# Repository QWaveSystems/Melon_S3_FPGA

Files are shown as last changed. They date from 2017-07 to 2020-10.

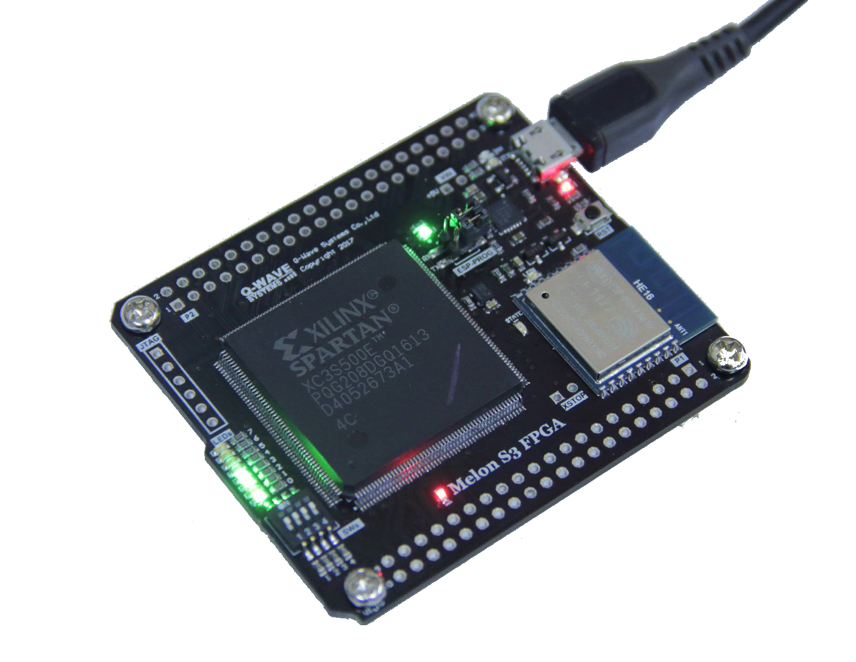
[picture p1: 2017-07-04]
Images/ms3.02.png

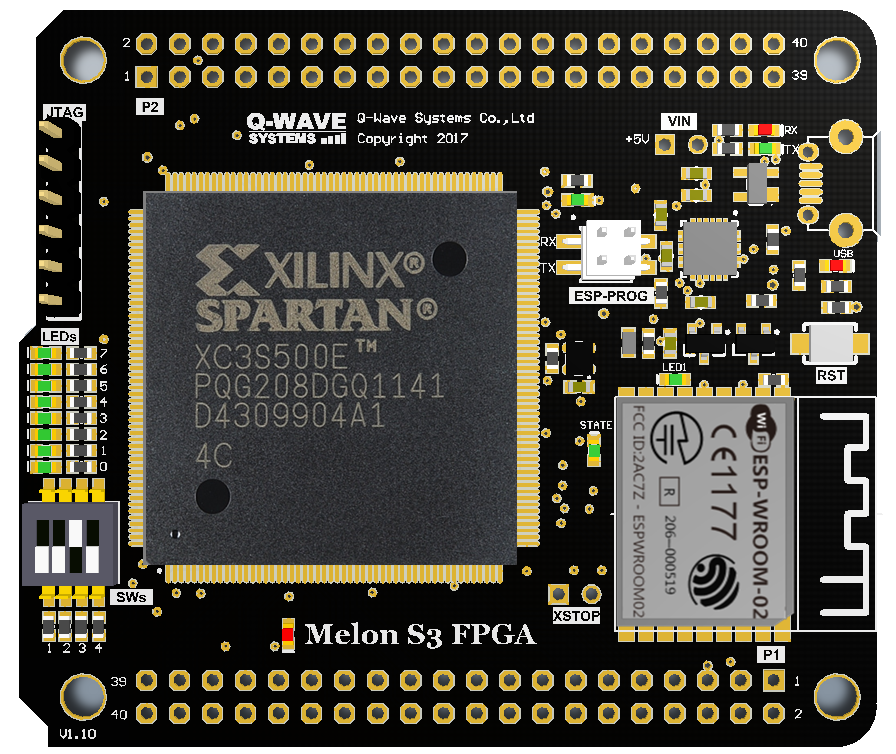
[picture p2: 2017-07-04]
Images/ms3.03.png

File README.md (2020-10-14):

# Melon S3 FPGA Development Board Hardware User Manual

# How to get a development board.

https://www.qwaveshop.com/en/product/340843/product-340843

# Community Support Forums

https://www.facebook.com/groups/244230302736445/

### Table of Contents
 
- [Introduction](#introduction)
- [Specification](#specification)
- [System Block Diagram](#system-block-diagram)
- [Board Overview](#board-overview)
- [ESP-PROG (TX/RX) Jumper Setting](#txrx-jumper-setting)
- [Pin Definition](#pin-definition)
- [Getting Started](#getting-started--starting-the-board-for-the-first-time)
- [OTA Programming (Upload .bit file to flash memory over the WiFi)](#ota-programming-upload-bit-file-to-flash-memory-over-the-wifi)
- [Write your own ESP8266 firmware.](#write-your-own-esp8266-firmware)
- [FPGA Development using Xilinx ISE Webpack](#fpga-development-using-xilinx-ise-webpack)
- [Install LabVIEW FPGA Driver](#install-melon-s3-fpga--labview-driver)
- [LabVIEW FPGA: Demo (Debug Mode over WiFi)](#labview-fpga-development-demo-debug-mode-over-wifi)
- [LabVIEW FPGA: Create a build specification to build a .bit file](#labview-fpga-development-create-a-build-specification-to-generate-a-bit-file)
- [LabVIEW FPGA: Additional Tools](#labview-fpga-development-additional-tools)
- [LabVIEW FPGA: Export .bit file](#labview-fpga-development-export-bit-file)
- [LabVIEW FPGA: Generate Control define for Arduino](#labview-fpga-development-generate-control-define-for-arduino)
- [LabVIEW FPGA: Host-Target Architecture: (Arduino MCU) <-> (FPGA)](#labview-fpga-development-host-target-architecture-arduino-mcu---fpga)
- [LabVIEW FPGA: Host-Target Architecture: (Raspberry Pi CPU) <-> (FPGA)](#labview-fpga-development-host-target-architecture-raspberry-pi-cpu---fpga)
- [Mechanical Specification](#mechanical-specification)
- [Download Board design files](#download-board-design-files)
- [License](#license)
- [Maintainer](#maintainer)

***

## Introduction

 The **Melon S3 FPGA is an open-source hardware (OSHW)**, expandable development board perfect for the learning digital circuit design and prototyping of your unique ideas. You can customize the capabilities of the FPGA with snap-on 40-pin "Raspberry Pi HAT". There are serveral shilds in the market offers a low cost module that can be purchased off the shelf. These shiled modules can be plugged directly to the Melon S3 FPGA board for the creation of powerful embedded and digital system applications.



## Specification

   - OTA (Over-The-Air) Download.bit file to FPGA over the WiFi
   - **Xilinx Spartan 3E FPGA (PQG208) - 500K gates**,
(73Kb Distributed RAM, 4 Digital Clock Manager (DCM), 20 Multipliers (18x18), 360 Kb Block RAM)
   - Onboard USB-UART (Silicon Labs) CP2104 for Configuration, Debugging and Power.
   - **MCU WROOM-02 (ESP8266), WiFi 2.4GHz + 32-bit MCU (Arduino Compatible)** Clock 80MHz, 50KB RAM, Integrated TCP/IP protocol stack.
   - Flash **4MB SPI Flash** which is **1MB for MCU Firmware** and **3MB for FPGA Bit space**.
   - 8 Users LEDs, 4 DIP Switch user button, 1 Reset button
   - Onboard FPGA clock 50MHz
   - GPIOs 56 PINs **3.3V Tolerant** - 40 PINs x2 (Raspberry Pi 40 PINs Compatible)
   - JTAG Port (*Optional for Program/Debugging)
   
   

[Back to top](#melon-s3-fpga-development-board-hardware-user-manual)

## System Block Diagram



In addition, The Melon S3 FPGA can be programmed using established development tools, such as [Xilinx ISE (Free: Webpack)](https://www.xilinx.com/products/design-tools/ise-design-suite/ise-webpack.html), [MATLAB HDL Coder/HDL Verifier](https://www.mathworks.com/solutions/hdl-code-generation-verification.html) and [National Instruments LabVIEW FPGA Toolkit](http://www.ni.com/labview/fpga/). Lastly, MCU ESP8266 (WROOM-02) can be programmed using Arduino IDE.

[Back to top](#melon-s3-fpga-development-board-hardware-user-manual)
  
## Board Overview
 
 **Front Side**
 

 
| Position | Reference | Description |
|:---:|:---:|:---|
| 1 | JTAG Port | Optional for Programing & Debuging using Xilinx ISE Software|
| 2 | FPGA | Xilinx FPGA Spartan 3E 500K|
| 3 | LEDs | x8 LED (Green)|
| 4 | DIP SWs | x4 DIP Switches|
| 5 | Pwr LED | 3.3V Power LED (Red)|
| 6 | XSTOP Jumper| FPGA code will STOP if Jumper added (Size 2.5"), Using this jumper as a FPGA stop pin (No jumper by default)|
| 7 | Status LED | User define LED (Green) at GPIO15 of ESP8266|
| 8 | MCU | WiFi SoC (ESP8266) Flash 4MB Version|
| 9 | Oscilator | ABRACON 50 MHz onboard oscilator (50ppm)|
| 10 | LED1 | User define LED (Green) at GPIO2 of ESP8266, This LED will be flashing during upload firmware to ESP8266|
| 11 | Reset Btn | Reset Button for ESP8266|
| 12 | TX/RX Jumper | TX/RX Jumper of ESP8266 and USB CP2104 (Size 2.0"), Refer Jumper setting section|
| 13 | USB IC | CP2104 UART to USB IC|
| 14 | USB LED | USB Plug-in LED Status (VUSB)|
| 15 | Done LED | FPGA Status LED if .bit file downloaded to FPGA without error|
| 16 | VIN 5V | External Power supply +5V can powered the board from this pin|
| 17 | TX/RX LEDs  | TX/RX LED Status of USB IC (CP2104)|
| 18 | USB Connector| USB Connector for +5V input for powered the board or Debug/Programming port for ESP8266|

[Back to top](#melon-s3-fpga-development-board-hardware-user-manual)

**Bottom Side** (Solder pad jumper for the users are willing to use with **Raspberry Pi Shileds**)



| Position | Reference | Description |
|:---:|:---:|:---|
| 1 | (JP2) RPi 3.3 V Jumper| Solder pad Jumper is "Open" by Default, But once the Melon FPGA and Raspberry Pi **Shields** stacked together **at P1 Port**, You can powered RPi **Shileds** board at 3.3V P1:1,P1:17 (3V3_RP) by using the power VUSB (5V) or VIN (5V) from Melon FPGA board, by setting the Jumper "Closed (Soldered)", Refer schematic for more information|
| 2 | HSWAP Jumper | Set the default state of FPGA Pins, Solder pad jumper is "Open"= Pull-down (by Default), Set the jumper pad to "Closed, (Soldered)"= All the FPGA pins are Pull-Up.|
| 3 | (JP1) Rpi 5V Jumper  |  Solder pad Jumper is "Open" by Default, But once the Melon FPGA and Raspberry Pi **Shields** are stacked together **at P1 Port**, if you want to powered RPi **Shields**  P1:2,P2:4 (5V_RP) by using the power VUSB (5V) or VIN (5V) from Melon FPGA board, by setting the Jumper "Closed (Soldered)", Refer schematic for more information|

[Back to top](#melon-s3-fpga-development-board-hardware-user-manual)

## TX/RX Jumper Setting

"ESP-PROGRAM" TX/RX Jumper is set to "Open" by Default, In order to re-program ESP8266 firmware, The both jumpers (TX/RX) need to be inserted (Closed).

USB TX/RX and ESP TX/RX pins also routed to FPGA refer the diagram below, You can writed the FPGA code to set jumper internally. In this case you can re-program the ESP8266 firmware without any jumpers.



[Back to top](#melon-s3-fpga-development-board-hardware-user-manual)

## Pin Definition



**Port1**

FPGA Pin Number (Pxx) vs Connector Pins **(RPi shileds can be connected to this port)**

| Description | Pin Number | Pin Number | Description |
|:---:|:---:|:---:|:---:|
| **+3V3_RP** Using with RPi shields need to set solder pad jumper at bottom side |**1** |**2** |**+5V_RP** Using with RPi shields need to set solder pad jumper at bottom side|
| P50 |3 |**4** |**+5V_RP** Using with RPi shields need to set solder pad jumper at bottom side|
| P49 |5 |**6** |**Ground**|
| P48 |7 |8 |P47|
| **Ground** |**9** |10 |P42|
| P41 |11 |12 |P40|
| P39 |13 |**14** |**Ground**|
| P36 |15 |16 |P35|
| **+3V3_RP** Using with RPi shields need to set solder pad jumper at bottom side |**17** |18 |P34|
| P35 |19 |**20** |**Ground**|
| P31 |21 |22 |P30|
| P29 |23 |24 |P28|
| **Ground** |**25** |26 |P25|
| P24 |27 |28 |P23|
| P22 |29 |**30** |**Ground**|
| P19 |31 |32 |P18|
| P16 |33 |**34** |**Ground**|
| P15 |35 |36 |P12|
| P11 |37 |38 |P9|
| **Ground** |**39** |40 |P8|
   
 **Port 1** : The FPGA pin constraints (.ucf) for Xilinx ISE and FPGA IO for LabVIEW aslo provide. 
   
     
  
[Back to top](#melon-s3-fpga-development-board-hardware-user-manual)
  
**Port2**

FPGA Pin Number (Pxx) vs Connector Pins

| Description | Pin Number | Pin Number | Description |
|:---:|:---:|:---:|:---:|
| **+3V3** |**1** |**2** |**+5V**|
| P153 |3 |**4** |**+5V**|
| P152 |5 |**6** |**Ground**|
| P150 |7 |8 |P151|
| **Ground** |**9** |10 |P147|
| P146 |11 |12 |P145|
| P144 |13 |**14** |**Ground**|
| P139 |15 |16 |P140|
| **+3V3** |**17** |18 |P138|
| P137 |19 |**20** |**Ground**|
| P133 |21 |22 |P132|
| P129 |23 |24 |P128|
| **Ground** |**25** |26 |P127|
| P126 |27 |28 |P123|
| P122 |29 |**30** |**Ground**|
| P120 |31 |32 |P119|
| P116 |33 |**34** |**Ground**|
| P115 |35 |36 |P113|
| P112 |37 |38 |P109|
| **Ground** |**39** |40 |P108|
   
 **Port 2** : The FPGA pin constraints (.ucf) for Xilinx ISE and FPGA IO for LabVIEW aslo provide.  
   
    
 
[Back to top](#melon-s3-fpga-development-board-hardware-user-manual)
 
## Getting Started : Starting the board for the first time

   - Plug-in the USB cable to the USB computer port to powered the board, You will get the 8-bit counter (up) at onboard LEDs with speed around 100ms.

  

   - Debugging the data at COM port, Put the "ESP-PROG" both jumper to the "Closed" position,
   
   
     
   - Open the Serial Monitor software > Select COM port > Set the buad rate to **"115200"**,Then pressed the "RESET" button on the board. This is what you will get from serial monitor.
   
     
   
   - Right now the board is act like **WiFi Access Point name "Melon-xxxxx"**, Re-scanning the WiFi, its will be appear on the network.
   - Connect to the **"Melon-xxxxx"** using the default password **"88888888"**
   - After that open the web browser, Then goto main webpage **"192.168.4.1"**
   
        
 
 [Back to top](#melon-s3-fpga-development-board-hardware-user-manual)
 
   - There are several command that already created for you to working with File Systems over the web browser. It is written using Arduino C/C++ ,Refer to shipped firmware source code in this repository ("Firmware" folder).
   
     - **./files**  (List the files inside flash memory)
     - **./startup** (Set the config file to load FPGA code at startup)
     - **./unstartup** (Unset the config file to load FPGA code at startup)
     - **./delete?file=[File Name]** (For example : http://192.168.4.1/delete?file=xx.bit)
     - **./[File Name]** To view or download the file (For example : http://192.168.4.1/xx.json)
   
   - For example we will try to lists the files that currently stored in flash memory. Type : **"http://192.168.4.1/files** You will see there are serveral files, The important one is **"Fpga.bit"** file, It's a FPGA bit file that currently running on the board right now. 

 

## OTA Programming (Upload .bit file to flash memory over the WiFi)
   
   - Download the .bit file from **"Bit_File/Fpga.bit"** from this repository. Save it in your local computer. (*It is a .bit file of 8-bit counter circuit that shipped with the board)*
   - Click the **"Choose File"**, > Select the **"Fpga.bit"**. > Click **"Update"**, The bit file will be transfer over the WiFi then upload diretly to flash memory, (You will get status "*Update Success!*", If it not please try again), After that board it will reset once, Finally you will see the FPGA start-up with the 8-bit counter circuit again.
   


[Back to top](#melon-s3-fpga-development-board-hardware-user-manual)

## Write your own ESP8266 firmware.
### (1/2) Install Arduino “QWAVE ESP8266 Board Package”

   - Download a Arduino IDE 1.8.x from "https://www.arduino.cc/en/Main/Software"
   - Goto "File > Preferences", Then add "http://ftp1.qwavesys.com/lvembedded/package_qwavesys_v2_index.json" > Click OK
   


 
   
   - Goto "Tools > Board> Boards Manager ", Install "Embedded LabVIEW Arduino by Qwavesys"
   
 
 
  
   
   - Once the installation finished, You can find the "Qwave ESP8266 (LabVIEW)" board.



[Back to top](#melon-s3-fpga-development-board-hardware-user-manual)

### (2/2) Start Writing your own ESP8266 firmware.

   - The shipped Melon S3 MCU firmware is located at **"Firmware/Firmware-MelonS3-v.0.3.ino"** from this repository, Open it with Arduino IDE. 
   
   - Let's modify the WiFi AP name to **"Melon-[Your Name]"** to indicate that this is your board in the WiFi network, You can change default password, if you want to..
   
   
   
[Back to top](#melon-s3-fpga-development-board-hardware-user-manual)
   
   - In order to program ESP8266, The jumper setting must be in the right position, . In this case I will leave both jumpers opened (Removed), Because FPGA shipped example bit file is already routed ESP TX/EX <----> USB TX/RX inside FPGA chip. Refer jumber setting section. [TX/RX Jumper Setting](#txrx-jumper-setting)
   
   - Connect the board to development PC, Select **"Qwave ESP8266 (LabVIEW)"** board, Speed **"921600"** (Test with Max Speed,If it not working try reduce the speed down to 115200), Select **COM port**.
   
   
   
   

## FPGA Development using Xilinx ISE Webpack

 [ISE® WebPACK™](https://www.xilinx.com/products/design-tools/ise-design-suite/ise-webpack.html) design software is the industry´s only FREE, fully featured front-to-back FPGA design solution. ISE WebPACK is the ideal downloadable solution for FPGA and offering HDL synthesis and simulation, implementation, device fitting, and JTAG programming. ISE WebPACK delivers a complete, front-to-back design flow providing instant access to the ISE features and functionality at no cost. Xilinx has created a solution that allows convenient productivity by providing a design solution that is always up to date with error-free downloading and single file installation. **After generated .bit file you can then upload it to the Melon S3 FPGA via WiFi.**
 
 - The shipped example for Xilinx ISE VHDL project is located at **"Example_VHDL/Test_LED.zip"** from this repository, Open it with Xilinx ISE. Refer the setting below **Spartan3E , XC3S500E, PQ208, Speed Grade (-4)**
 
   
   
  - At the **LED_SW.vhd**, it is very simple VHDL example the reading the status of DIP switch and display at onboard LEDs.
  
   
  
  - The **Melon_S3.ucf** files also provide for pin constraints.
  
   
   
   - After run **Synthesize > Translate > Place &Route > Generate bit file** , Then you will get **led_sw.bit**, Please rename to "**Fpga.bit**", Then you can use [OTA Programming (Upload .bit file to flash memory over the WiFi)](#ota-programming-upload-bit-file-to-flash-memory-over-the-wifi) method to download a bit file to flash memory and run at FPGA.
   
   
      
[Back to top](#melon-s3-fpga-development-board-hardware-user-manual)

## Install Melon S3 FPGA : LabVIEW Driver

The [NI LabVIEW FPGA Module](http://www.ni.com/labview/fpga/) extends the LabVIEW graphical development platform to target FPGAs. LabVIEW FPGA gives developers the ability to more efficiently and effectively design complex systems by providing a highly integrated development environment, a large ecosystem of IP libraries, a high-fidelity simulator, and debugging features.
 
   - Before install LabVIEW driver , Please close all LabVIEW application. In this tutorial is assumed that you already have **LabVIEW 2014 (32bit) & LabVIEW 2014 FPGA Toolkit (For Windows)** installed in local machine.

   - Extract the folder **QwaveSys** to path. "C:\Program Files (x86)\National Instruments\LabVIEW 2014\Targets\NI\FPGA\QwaveSys"

   

   - Extract the folder "**MelonS3**" to path. "C:\Program Files (x86)\National Instruments\LabVIEW 2014\vi.lib\FPGAPlugInAG\Melon-S3"

   
   
   - At Windows Dev Machine: Copy "**QwaveFpgaLv.dll**" to systems path. "C:\Windows\System32\QwaveFpgaLv.dll"

   

   - **Remove "resource_cache.xml"** the file below, Before staring LabVIEW ONLY for the first time use. "C:\Program Files (x86)\National Instruments\LabVIEW 2014\Targets\NI\FPGA\resource_cache.xml"

   

   - Extract the folder "**HDL**" to path. "C:\Program Files (x86)\National Instruments\LabVIEW 2014\rvi\HDL"

   

   - Start **LabVIEW > Create LabVIEW Empty Project**, Under **"My Computer"** Select **"Target and Device**, you will find **"Melon-S3" under "3rd Party group"**
   
   
   
   
   
   - Right click at **"Melon-S3"** select **"New > FPGA I/O"** you will find available IOs for Melon-S3 ready to use within the project. Add them all if you want.
   
   
   
   
 
 [Back to top](#melon-s3-fpga-development-board-hardware-user-manual)

## LabVIEW FPGA Development: Demo (Debug Mode over WiFi)

  - The shipped example for LabVIEW FPGA is located at **"Example_LabVIEW/Test_Counter.zip"** from this repository, Open the project (**LED.lvproj**) file with LabVIEW.
 
  - Connect development PC with "**Melon-S3-xx**" WiFi AP. Refer to this step [Getting Started](#getting-started--starting-the-board-for-the-first-time)
  
  - Clcik **Run** button, Then observed the LabVIEW front panel and Onboard LEDs, Then you can adjust the **Count(mSec)** value to see the result in debugging mode.
    
  

[Back to top](#melon-s3-fpga-development-board-hardware-user-manual)

## LabVIEW FPGA Development: Create a build specification to generate a .bit file.

   -  **Right Click** at the VI (.vi) > **Create Build Specification**
  
  
  
   -  Under **Build Specification** > **Right Click** > Select : **Properties**
  
  
    
   -  Select **Run when loaded to FPGA**
    
  
   
   -  **Right Click** then, Select **Build**
   
  
   
   -  Select the **Use the Local Compile server** or Network/Cloud server. ([NI LabVIEW 2014 FPGA Module Xilinx Compilation Tools for Windows](http://www.ni.com/download/labview-fpga-module-2014/4845/en/) is required for local compilation. After finished you will get the output bit file at **"FPGA Bitfiles"** folder.
   
  
  
  
    
  

[Back to top](#melon-s3-fpga-development-board-hardware-user-manual)

## LabVIEW FPGA Development: Additional Tools.

   - **Right Click at the VI** you will get additional tools fo Melon S3 FPGA:
     
        - **Gen Bit File...** (Generate a bit file from build specification)
        - **Download VI To Flash Memory** (Download bit file to flash memory over WiFi, This will be done automatically.)
        - **Set FPGA Download As Startup** (Set FPGA code at startup, This action will be set "startup=1" at config.json file)
        - **Unset FPGA Download As Startup** (Unset FPGA code at startup, This action will be set "startup=0" at config.json file)
        - **Get Controls Define For Arduino** (Lists all LabVIEW front panel/controls for Arduino interface, Refer more detail to the next topic)
         - **Reboot** To view or download the file (This will send FPGA "reboot" command to the Melon FPGA board)

  

[Back to top](#melon-s3-fpga-development-board-hardware-user-manual)

## LabVIEW FPGA Development: Export .bit file.

   -  Select **"Gen Bit File.."** function, Then you will get **Fpga.bit** locaed at "FPGA Bitfiles" folder.

  

[Back to top](#melon-s3-fpga-development-board-hardware-user-manual)

## LabVIEW FPGA Development: Generate Control define for Arduino.

  -  Select **"Get Controls Define For Arduino"** function, Then you will get front panel control/indicator define to use in Arduino Code, Copy them and place at the top of Arduino C/C++ code. Refer next topic for example.

  

  

[Back to top](#melon-s3-fpga-development-board-hardware-user-manual)

## LabVIEW FPGA Development: Host-Target Architecture: (Arduino MCU) <-> (FPGA).

Using Arduino IDE you can write your own firmware running in MCU (WROOM-02), This allows your FPGA designs to talk to the microcontroller, giving you develop the MCU + FPGA for co-processing application.

  

[Back to top](#melon-s3-fpga-development-board-hardware-user-manual)

## LabVIEW FPGA Development: Host-Target Architecture: (Raspberry Pi CPU) <-> (FPGA).

  

[Back to top](#melon-s3-fpga-development-board-hardware-user-manual)

## Mechanical Specification

   

## Download Board design files

PDF https://github.com/QWaveSystems/Melon_S3_FPGA/tree/master/PDF

Schematic & PCB https://github.com/QWaveSystems/Melon_S3_FPGA/tree/master/Schematic_PCB

Firmware (Arduino C/C++) https://github.com/QWaveSystems/Melon_S3_FPGA/tree/master/Firmware

**Xilinx ISE support files**

https://github.com/QWaveSystems/Melon_S3_FPGA/blob/master/UCF%20File/Melon_S3.ucf

**Xilinx ISE project examples**

https://github.com/QWaveSystems/Melon_S3_FPGA/tree/master/Example_VHDL

**LabVIEW FPGA (2014) Examples**

8 bit Counter Example https://github.com/QWaveSystems/Melon_S3_FPGA/tree/master/Example_LabVIEW

8 bit Counter with Raspberry Pi Interface https://github.com/QWaveSystems/Melon_S3_FPGA/tree/master/Example_LabVIEW_RaspberryPi_LINX

[Back to top](#melon-s3-fpga-development-board-hardware-user-manual)

## LICENSE

-Schematics and PCB ﬁles is licensed under a Creative Commons Attribution-ShareAlike 4.0 International License.
You should have received a copy of the license along with this work. If not, see: http://creativecommons.org/licenses/by-sa/4.0

[Back to top](#melon-s3-fpga-development-board-hardware-user-manual)

## Maintainers

Amornthep Phunsin <amornthep@qwavesys.com>

[Back to top](#melon-s3-fpga-development-board-hardware-user-manual)

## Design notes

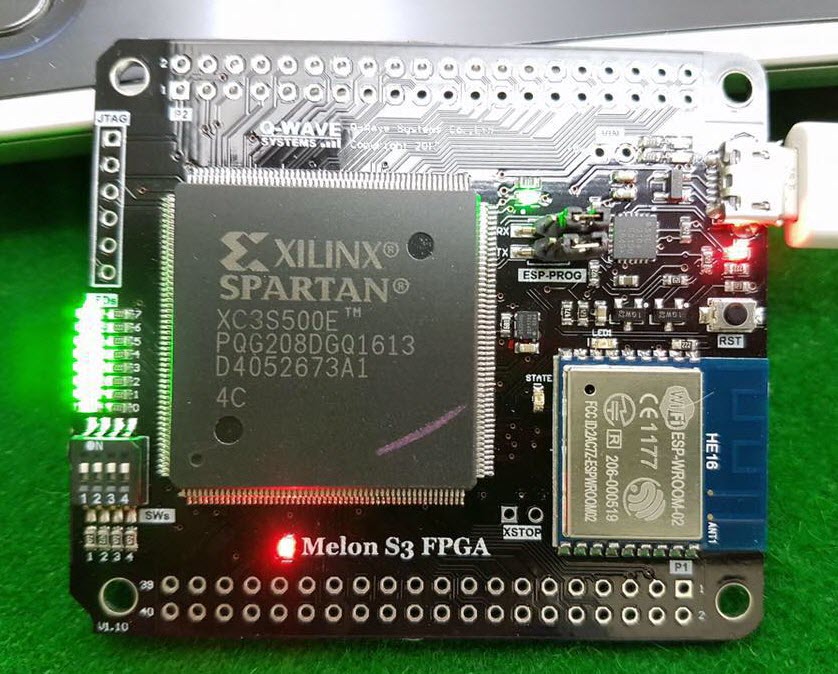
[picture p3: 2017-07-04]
Images/ms3.01.jpg

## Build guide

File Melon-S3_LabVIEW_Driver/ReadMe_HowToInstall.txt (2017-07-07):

Before install driver , Please close all LabVIEW application.

1. Extract the folder "QwaveSys" to below path
C:\Program Files (x86)\National Instruments\LabVIEW 2014\Targets\NI\FPGA\QwaveSys

2. Extract the folder "MelonS3" to below path 
C:\Program Files (x86)\National Instruments\LabVIEW 2014\vi.lib\FPGAPlugInAG\Melon-S3

3. At Windows Dev Machine: Copy "QwaveFpgaLv.dll" to systems path.
C:\Windows\System32\QwaveFpgaLv.dll

4.Remove the file below, Before staring LabVIEW only for the first time use.
C:\Program Files (x86)\National Instruments\LabVIEW 2014\Targets\NI\FPGA\resource_cache.xml

5.Extract the folder "HDL" to below path.
C:\Program Files (x86)\National Instruments\LabVIEW 2014\rvi\HDL

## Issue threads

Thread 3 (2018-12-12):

melons3 firmware problem with qwavefpga.h

imangholizadeh, 2018-12-12:
I program my esp8266 board (ESP8266 ESP-12E NODEMCU ) with Firmware-MelonS3-v.0.3.ino without any change and  then i cant see any access point. i debuged code and i saw  functions that realated to qwavefpga.h  not runing. why?
i dont have wroom-2 and i want to use ESP8266 ESP-12E NODEMCU instad of  wroom-2.can i do this? how?

pamornthep, 2018-12-13:
The code "Firmware-MelonS3-v.0.3.ino " haven't tested with ESP-12E. I am not sure what is the problem. I only do tested with WROOM-02, The WROOM-02 module is difference from ESP-12E in term of hardware spec,flash memory,pin assignment and etc...

imangholizadeh, 2018-12-13:
thanks for your replay. I know WROOM-02 module is difference from ESP-12E and i change spec pin configuration and etc ... but no answer. my problem is There are no WROOM-02 in my country, and if they exist, they are much more expensive than ESP-12E. if i has qwavefpga.ccp i can write this firmware for other arduino board but in melon s3 project qwavefpga.ccp is hidden in static library "libqwavesys.a " located in "\qwavesys\hardware\esp8266\2.3.0-2\tools\sdk\lib" and i can not access to source of "libqwavesys.a " . if melon s3 project is open source  I expected that is not hidden. If you can help me anyway, I will thank you for it.

johnmayer21, 2018-12-23:
@imangholizadeh They can not tell you this because they are just copying our work and they are not aware of it themselves.
This science is only available to our company, and they will always be illegal in our area.

johnmayer21, 2018-12-23:
@imangholizadeh They can not tell you this because they are just copying our work and they are not aware of it themselves.
This science is only available to our company and they will always follow us.

sdikiy, 2019-02-06:
Very strange situation.
The project claims GPL support, and in fact most of the code is hidden in a static library.
https://github.com/QWaveSystems/Melon_S3_FPGA/blob/master/Firmware/License.md
Very strange project ...

imangholizadeh, 2019-02-14:
Yes Very strange project ...and we can not use that because all required code is hidden in a static library.
if you want to share some information with together you can send me email.
Email address: imangholizadeh68@gmail.com

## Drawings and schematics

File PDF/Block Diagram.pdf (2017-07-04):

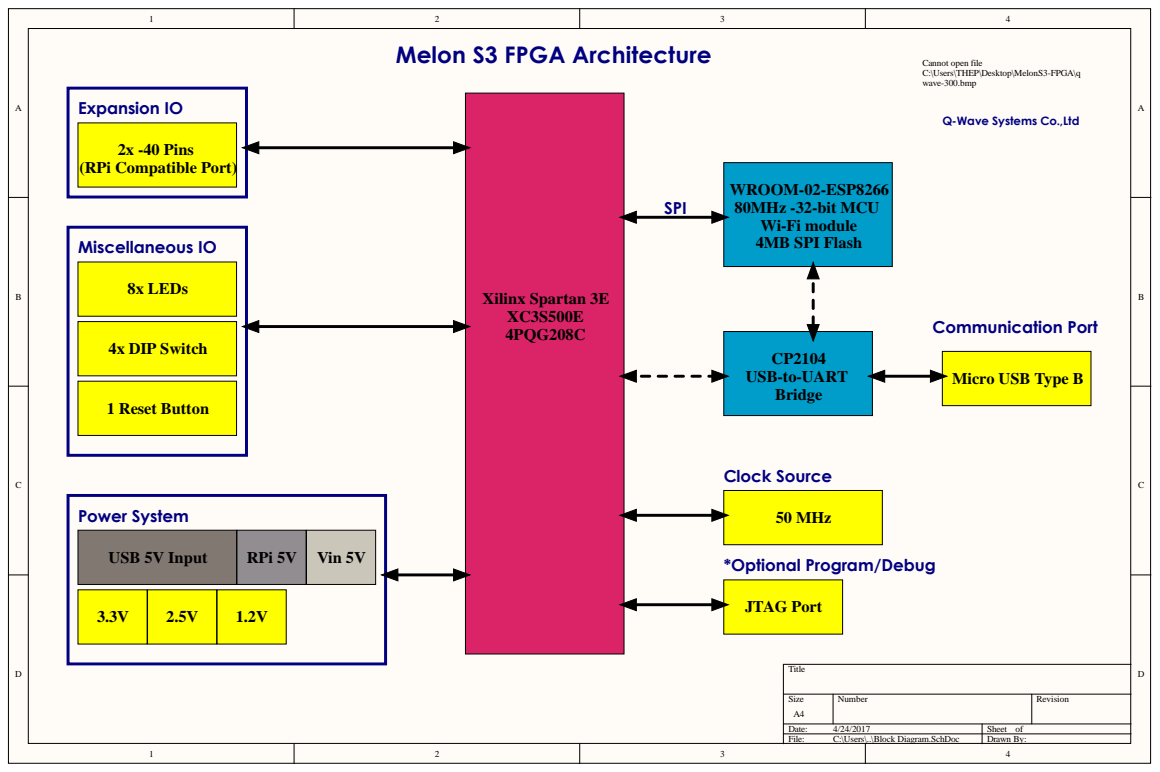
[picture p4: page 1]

C:\Users\THEP\Desktop\MelonS3-FPGA\q
wave-300.bmp

Q-Wave Systems Co.,Ltd

USB 5V Input | RPi 5V | Vin 5V

Size A4 | Number | Revision

Date: 4/24/2017 | Sheet of
File: C:\Users\..\Block Diagram.SchDoc | Drawn By:

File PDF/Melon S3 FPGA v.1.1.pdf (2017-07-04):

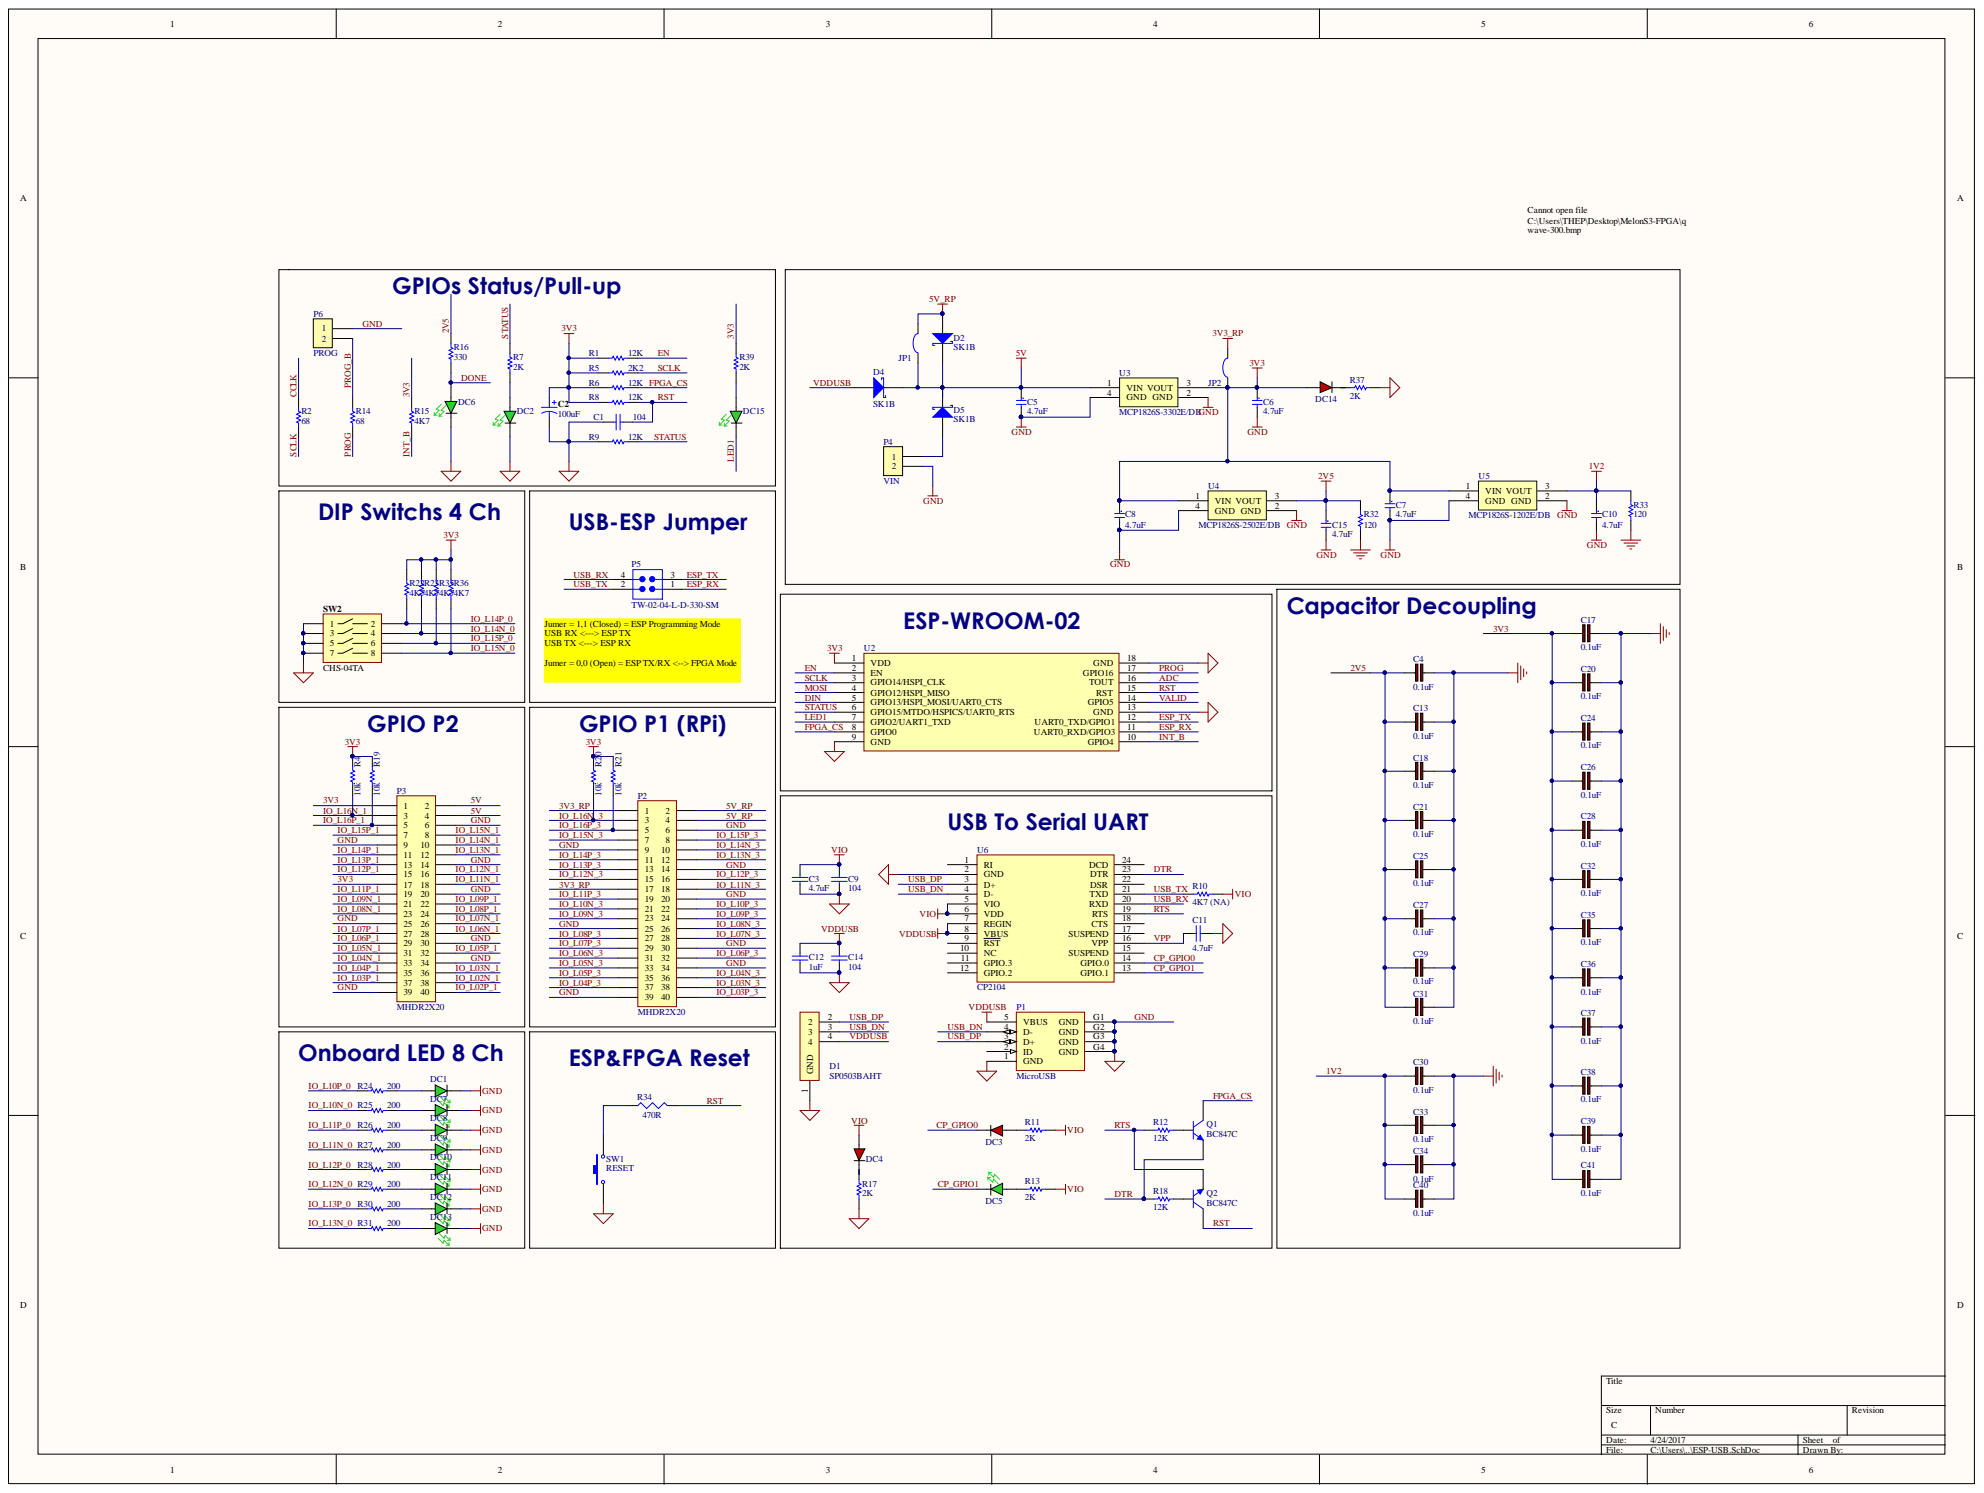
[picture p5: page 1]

Cannot open file
C:\Users\THEP\Desktop\MelonS3-FPGA\q
wave-300.bmp

GPIOs Status/Pull-up

Jumer = 1,1 (Closed) = ESP Programming Mode
USB RX <---> ESP TX
USB TX <---> ESP RX

IO_L15P_0
IO_L15N_0

Jumer = 0,0 (Open) = ESP TX/RX <--> FPGA Mode

GPIO P2 3V3 P3 | GPIO P1 (RPi) 3V3 | STATUS LED1 | GPIO15/MTDO/HSPICS/UART0_RTS 6 GPIO2/UART1_TXD 7 | ESP_TX

USB To Serial UART


C:\Users\THEP\Desktop\MelonS3-FPGA\q
wave-300.bmp

Q-Wave Systems Co.,Ltd

USB 5V Input | RPi 5V | Vin 5V

Size A4 | Number | Revision

Date: 4/24/2017 | Sheet of
File: C:\Users\..\Block Diagram.SchDoc | Drawn By:

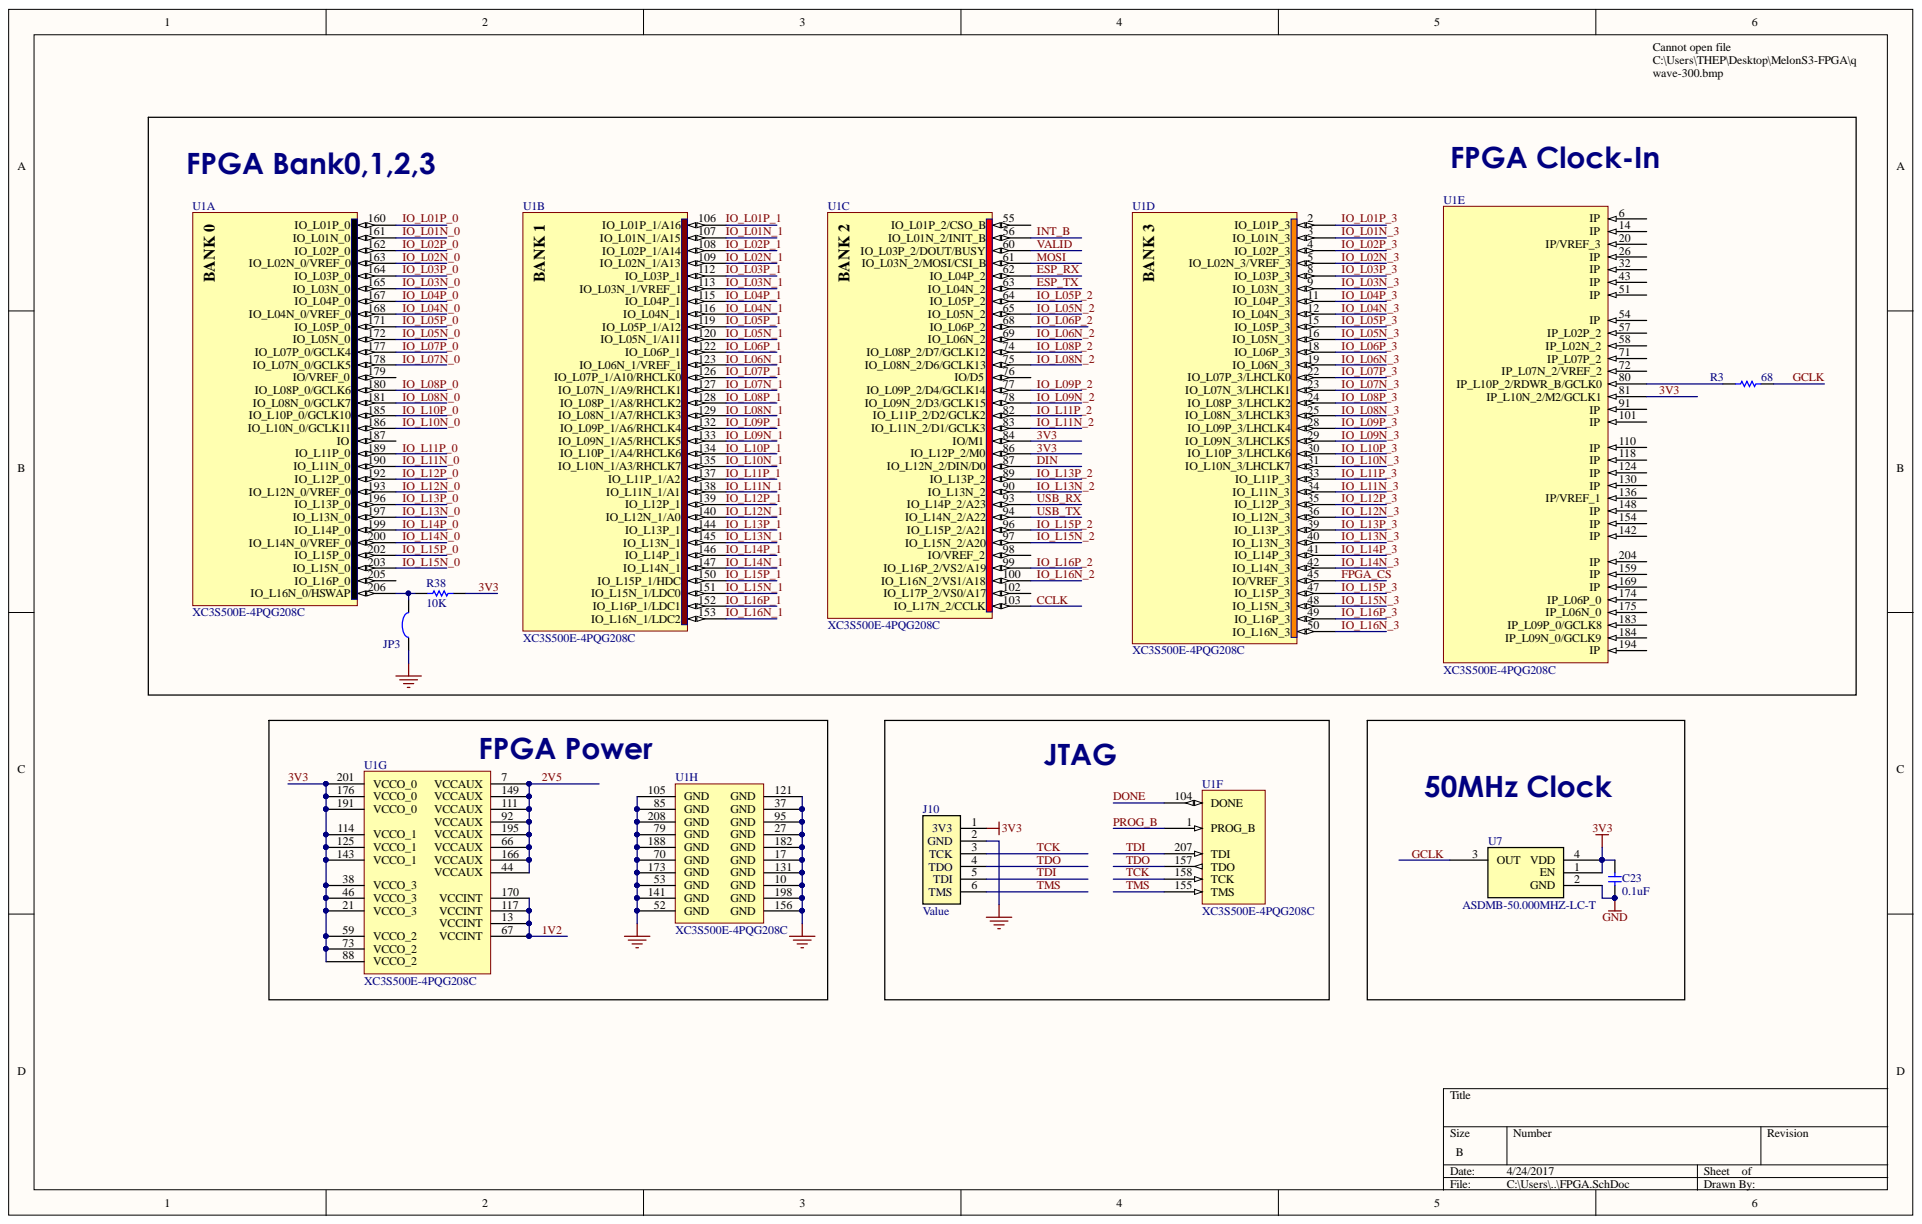
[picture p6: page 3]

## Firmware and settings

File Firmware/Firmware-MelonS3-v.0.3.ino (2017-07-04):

// Qwave ESP8266 (LabVIEW) 4M(3M SPIFFS)

#include <ESP8266WiFi.h>
#include <WiFiClient.h>
#include <ESP8266WebServer.h>
#include <WiFiUdp.h>
#include <ArduinoJson.h>
#include <FS.h>

// remove comment when using soft AP mode
#define SOFT_AP
#define DEVICE_NAME "QWAVE"

#define DBG_OUTPUT_PORT   Serial

#ifdef SOFT_AP
// Soft-AP Config
String ssid = "MelonS3";
String password = "88888888";
#else
// Network
String ssid = "";
String password = "";
#endif

#include "QwaveFpga.h"
QwaveFpga Fpga;
String FpgaStart;

extern "C" {
  #include "user_interface.h"
}

const char* bitfileupload = "<h2>FPGA Bit File Upload</h2><form method='POST' action='/' enctype='multipart/form-data'><input type='file' name='update'><input type='submit' value='Update'></form>";

ESP8266WebServer server(80);
WiFiUDP udp;

// buffers for receiving and sending data
char packetBuffer[UDP_TX_PACKET_MAX_SIZE]; //buffer to hold incoming packet,
String ReplyBuffer;

// local port to listen for UDP packets
unsigned int localPort = 4097;

File fsUploadFile;

String inputString = "";         // a string to hold incoming data
boolean stringComplete = false;  // whether the string is complete

String macToStr(const uint8_t* mac)
{
  String result;
  for (int i = 0; i < 6; ++i) {
    result += String(mac[i], 16);
  }
  result.toUpperCase();
  return result;
}

String loadConfig(String fname, String field) {
  File configFile = SPIFFS.open("/"+fname, "r");
  if (!configFile) {
    DBG_OUTPUT_PORT.println("Failed to open "+fname+" file!");
    return "";
  }

  size_t size = configFile.size();
  if (size > 1024) {
    DBG_OUTPUT_PORT.println("Config file size is too large");
    return "";
  }

  // Allocate a buffer to store contents of the file.
  std::unique_ptr<char[]> buf(new char[size]);

  // We don't use String here because ArduinoJson library requires the input
  // buffer to be mutable. If you don't use ArduinoJson, you may as well
  // use configFile.readString instead.
  configFile.readBytes(buf.get(), size);

  StaticJsonBuffer<200> jsonBuffer;
  JsonObject& json = jsonBuffer.parseObject(buf.get());

  if (!json.success()) {
    DBG_OUTPUT_PORT.println("Failed to parse config file");
    return "";
  }

  const char* _data = json[field];

  DBG_OUTPUT_PORT.print("Loaded "+field+": ");
  DBG_OUTPUT_PORT.println(_data);

  return _data;
}

bool saveConfig(String fname, String field, String value ) {
  StaticJsonBuffer<200> jsonBuffer;
  JsonObject& json = jsonBuffer.createObject();
  json[field] = value;

  File configFile = SPIFFS.open("/"+fname, "w");
  if (!configFile) {
    DBG_OUTPUT_PORT.println("Failed to open config file for writing");
    return false;
  }

  json.printTo(configFile);
  return true;
}

//format bytes
String formatBytes(size_t bytes){
  if (bytes < 1024){
    return String(bytes)+"B";
  } else if(bytes < (1024 * 1024)){
    return String(bytes/1024.0)+"KB";
  } else if(bytes < (1024 * 1024 * 1024)){
    return String(bytes/1024.0/1024.0)+"MB";
  } else {
    return String(bytes/1024.0/1024.0/1024.0)+"GB";
  }
}

String getContentType(String filename){
  if(server.hasArg("download")) return "application/octet-stream";
  else if(filename.endsWith(".htm")) return "text/html";
  else if(filename.endsWith(".html")) return "text/html";
  else if(filename.endsWith(".css")) return "text/css";
  else if(filename.endsWith(".js")) return "application/javascript";
  else if(filename.endsWith(".png")) return "image/png";
  else if(filename.endsWith(".gif")) return "image/gif";
  else if(filename.endsWith(".jpg")) return "image/jpeg";
  else if(filename.endsWith(".ico")) return "image/x-icon";
  else if(filename.endsWith(".xml")) return "text/xml";
  else if(filename.endsWith(".pdf")) return "application/x-pdf";
  else if(filename.endsWith(".zip")) return "application/x-zip";
  else if(filename.endsWith(".gz")) return "application/x-gzip";
  else if(filename.endsWith(".svg")) return "image/svg+xml";
  return "text/plain";
}

bool handleFileRead(String path){
  DBG_OUTPUT_PORT.println("handleFileRead: " + path);
  if(path.endsWith("/")) path += "index.htm";
  String contentType = getContentType(path);
  String pathWithGz = path + ".gz";
  if(SPIFFS.exists(pathWithGz) || SPIFFS.exists(path)){
    if(SPIFFS.exists(pathWithGz))
      path += ".gz";
    File file = SPIFFS.open(path, "r");
    size_t sent = server.streamFile(file, contentType);
    file.close();
    return true;
  }
  return false;
}

void handleListFiles()
{
  String FileList = "File List:\n";

  Dir dir = SPIFFS.openDir("/");
  DBG_OUTPUT_PORT.println("File List:");
  while (dir.next())
  {
    String FileName = dir.fileName();
    File f = dir.openFile("r");
    String FileSize = formatBytes(f.size());
    int whsp = 6-FileSize.length();
    while(whsp-->0)
    {
      DBG_OUTPUT_PORT.print(" ");
      FileList += " ";
    }
    DBG_OUTPUT_PORT.println(FileSize+" "+FileName);
    FileList += FileSize+" "+FileName+"\n";
  }     
  server.sendHeader("Connection", "close");
  server.sendHeader("Access-Control-Allow-Origin", "*");
  server.send(200, "text/plain", FileList);
}

void SerialEvent() {
  while (Serial.available()) {
    // get the new byte:
    char inChar = (char)Serial.read();
  
    // if the incoming character is a newline, set a flag
    // so the main loop can do something about it:
    if (inChar == '\n') {
    //if (inChar == 0x1A) {
      stringComplete = true;
    }
    else {
      // add it to the inputString:
      inputString += inChar;
    }
  }
}

void setup(void){

  // Init FPGA Interface
  Fpga.begin();
  
  ESP.wdtEnable(15000); // make the watch dog timeout 15 seconds
  
  DBG_OUTPUT_PORT.begin(115200);
  DBG_OUTPUT_PORT.setDebugOutput(false);
  DBG_OUTPUT_PORT.print("\r\n");
  
  WiFi.disconnect();
  
  SPIFFS.begin();
  {
    Dir dir = SPIFFS.openDir("/");
    while (dir.next()) {    
      String fileName = dir.fileName();
      size_t fileSize = dir.fileSize();
      DBG_OUTPUT_PORT.printf("FS File: %s, size: %s\n", fileName.c_str(), formatBytes(fileSize).c_str());
    }
    DBG_OUTPUT_PORT.printf("\n");
  }

  FpgaStart = loadConfig("config.json","startup");
  if (FpgaStart == "") {
    saveConfig("config.json", "startup", "1" );
  } else if (FpgaStart == "0") {
    DBG_OUTPUT_PORT.println("Skip Fpga Load!");
  } else if (FpgaStart == "1") {
    DBG_OUTPUT_PORT.println("Loading Fpga...");
    Fpga.FpgaLoad("/Fpga.bit");
  }

  uint8_t mac[6];
  wifi_get_macaddr(STATION_IF, mac);
  ReplyBuffer = String(DEVICE_NAME) + "::" + macToStr(mac);

#ifdef SOFT_AP  
  //WIFI INIT
  WiFi.mode(WIFI_AP);
  ssid += String("-") + String(ESP.getChipId(), HEX);
  WiFi.softAP(ssid.c_str(), password.c_str());
  
  IPAddress myIP = WiFi.softAPIP();
  DBG_OUTPUT_PORT.println("*** Soft AP Started ***");
  DBG_OUTPUT_PORT.print("WiFi SSID: ");
  DBG_OUTPUT_PORT.println(ssid);
  DBG_OUTPUT_PORT.print("IP Address: ");
  DBG_OUTPUT_PORT.println(myIP);
  ReplyBuffer += " - "+String(myIP[0])+"."+String(myIP[1])+"."+String(myIP[2])+"."+String(myIP[3]);
#else
  DBG_OUTPUT_PORT.print("Connecting to ");
  DBG_OUTPUT_PORT.println(ssid);
  WiFi.begin(ssid.c_str(), password.c_str());
  while (WiFi.status() != WL_CONNECTED) {
    delay(500);
    DBG_OUTPUT_PORT.print(".");
  }
  IPAddress myIP = WiFi.localIP();
  DBG_OUTPUT_PORT.println("\nWiFi connected");  
  DBG_OUTPUT_PORT.print("IP Address: ");
  DBG_OUTPUT_PORT.println(myIP);
  ReplyBuffer += " - "+String(myIP[0])+"."+String(myIP[1])+"."+String(myIP[2])+"."+String(myIP[3]);
#endif

  udp.begin(localPort);
  DBG_OUTPUT_PORT.print("Starting UDP ");
  DBG_OUTPUT_PORT.print("on port: ");
  DBG_OUTPUT_PORT.println(udp.localPort());
  
  server.onNotFound([](){
    if(!handleFileRead(server.uri())) {
      server.send(404, "text/plain", "FileNotFound");
    }
  });

  //list files
  server.on("/files", HTTP_GET, handleListFiles);

  server.on("/reboot", HTTP_GET, [](){
    server.send(200, "text/html", "rebooting in 3 seconds...");
    delay(3000);
    ESP.restart();
  });

  server.on("/startup", HTTP_GET, [](){
    saveConfig("config.json", "startup", "1" );
    server.send(200, "text/html", "done.");
  });

  server.on("/unstartup", HTTP_GET, [](){
    saveConfig("config.json", "startup", "0" );
    server.send(200, "text/html", "done.");
  });
  
  server.on("/delete", HTTP_GET, [](){
      if (server.hasArg("file")) {
        String path = "/" + server.arg("file");
        SPIFFS.remove(path);
        server.send(200, "text/html", "deleted " + path);
      }
      else {
        server.send(404, "text/plain", "Please following format: /delete?file=FileName");
      }
  });
  
  server.on("/", HTTP_GET, [](){
      server.sendHeader("Connection", "close");
      server.sendHeader("Access-Control-Allow-Origin", "*");
      server.send(200, "text/html", bitfileupload);
  });
    
  server.on("/", HTTP_POST, [](){
      server.sendHeader("Connection", "close");
      server.sendHeader("Access-Control-Allow-Origin", "*");
      server.send(200, "text/plain", (Update.hasError())?"Update Failed!":"Update Success!");
  },[]() {
      HTTPUpload& upload = server.upload();
      if(upload.status == UPLOAD_FILE_START){
        DBG_OUTPUT_PORT.printf("Update: %s\n", upload.filename.c_str());
        String path = "/" + upload.filename;
        SPIFFS.remove(path);
        fsUploadFile = SPIFFS.open(path, "w");
        Fpga.SaveFile_Init();
      } else if(upload.status == UPLOAD_FILE_WRITE){
        if(fsUploadFile) {
          Fpga.SaveFile_Encypt(upload.buf, upload.currentSize);
          fsUploadFile.write(upload.buf, upload.currentSize);
        }
      } else if(upload.status == UPLOAD_FILE_END){
        if(fsUploadFile) {
          DBG_OUTPUT_PORT.printf("Upload Success: %u\n", upload.totalSize);
          fsUploadFile.close();
          Fpga.FpgaLoad("/" + upload.filename);
        }
      }
      yield();
  });

  server.on("/fpga-run", HTTP_POST, [](){
      server.sendHeader("Connection", "close");
      server.sendHeader("Access-Control-Allow-Origin", "*");
      server.send(200, "text/plain", (Update.hasError())?"Run Failed!":"Run Success!");

  },[]() {
      HTTPUpload& upload = server.upload();
      if(upload.status == UPLOAD_FILE_START){
        DBG_OUTPUT_PORT.printf("Download: %s\n", upload.filename.c_str());

        // Init FPGA
        Fpga.Transfer_Init();
        
      } else if(upload.status == UPLOAD_FILE_WRITE){
        
        int count = upload.currentSize;
        Fpga.Transfer(count, upload.buf);
        
      } else if(upload.status == UPLOAD_FILE_END){
        Fpga.Transfer_End();
        DBG_OUTPUT_PORT.println("done.");
        DBG_OUTPUT_PORT.println();
      }
      yield();
  });
    
  server.begin();
  DBG_OUTPUT_PORT.println("HTTP server started");
  
}

void loop(void){
  ESP.wdtFeed();
  server.handleClient();

  // UDP Communication
  int packetSize = udp.parsePacket();
  if (packetSize)
  {
    /*Serial.print("Received packet of size ");
    Serial.println(packetSize);
    Serial.print("From ");
    IPAddress remote = udp.remoteIP();
    for (int i = 0; i < 4; i++)
    {
      Serial.print(remote[i], DEC);
      if (i < 3)
      {
        Serial.print(".");
      }
    }
    Serial.print(", port ");
    Serial.println(udp.remotePort());*/

    // read the packet into packetBufffer
    udp.read(packetBuffer, UDP_TX_PACKET_MAX_SIZE);
    packetBuffer[packetSize] = '\0';
    
    //Serial.println("Contents:");
    //Serial.println(packetBuffer);

    String inputString = String(packetBuffer);

    // send a reply, to the IP address and port that sent us the packet we received
    udp.beginPacket(udp.remoteIP(), udp.remotePort());
    
    if(inputString.startsWith("#Melon-S3")) {
      udp.write(ReplyBuffer.c_str());
    }
    else if(inputString.startsWith("/fpga-info")) {
      udp.write("Dev1,MelonS3Fpga,Melon-S3");
    }
    else if(inputString.startsWith("/fpga-setasstartup")) {
      saveConfig("config.json", "startup", "1" );
      udp.write("set fpga run as startup.");
    }
    else if(inputString.startsWith("/fpga-unsetasstartup")) {
      saveConfig("config.json", "startup", "0" );
      udp.write("unset fpga run as startup.");
    }
    else if(inputString.startsWith("/fpga-reboot")) {
      udp.write("Rebooting...");
      udp.endPacket();
      delay(3000);
      ESP.restart();
    }
    else if(inputString.startsWith("/fpga-busreset")) {
      Fpga.BusReset();;
      udp.write("done.");
    }
    else if(inputString.startsWith("/fpga-write?addr=")) {
      char addrReg[5], Data[11];
      int dd = inputString.indexOf('&')+1;
      inputString.substring(17).toCharArray(addrReg, (dd-17));
      inputString.substring(dd+5).toCharArray(Data, 11);
      Fpga.writeRegister(atoi(addrReg), strtoul(Data, '\0', 10));
      udp.write(Data);
    }
    else if(inputString.startsWith("/fpga-read?addr=")) {
      char addrReg[5];
      inputString.substring(16).toCharArray(addrReg, 5);
      if( Fpga.getRegister(atoi(addrReg)) ) {
        uint32_t oData = (uint32_t)Fpga.data.bit32[0];
        udp.write(String(oData).c_str());
      }
      else {
        udp.write("error!");
      }
    }
    else if(inputString.startsWith("/fpga-load")) {
      Fpga.FpgaLoad("/Fpga.bit");
      udp.write("done.");
    }
    else {
      udp.write("error!");
    }
    udp.endPacket();
  }

  // UART Communication
  SerialEvent();
  if (stringComplete) {
    int numCommand = inputString.indexOf(' ') + 1;
    
    if (inputString.startsWith("Reg?")) {
      if(numCommand == 5) {
        char addrReg[5];
        inputString.substring(numCommand).toCharArray(addrReg, 5);
        if( Fpga.getRegister(atoi(addrReg)) ) {
          Serial.println((uint32_t)Fpga.data.bit32[0]);
        }
        else {
          Serial.println("error!");
        }
      }
      else {
        Serial.println("Reg? [Register Address]");
      }
    }
    else if (inputString.startsWith("Reg")) {
      int cm = inputString.indexOf(',', numCommand)+1;
      if(numCommand == 4 && cm > 5) {
        char addrReg[5], Data[11];
        inputString.substring(numCommand).toCharArray(addrReg, (cm-numCommand));
        inputString.substring(cm).toCharArray(Data, 11);
        Fpga.writeRegister(atoi(addrReg), strtoul(Data, '\0', 10));
      }
      else {
        Serial.println("Reg [Register Address],[Data]");
      }
    }
    else if (inputString.startsWith("FpgaLoad")) {
      Fpga.FpgaLoad("/Fpga.bit");
    }
    else if (inputString.startsWith("bReset")) {
      Fpga.BusReset();
    }
    else if (inputString.startsWith("viRun")) {
      if( !Fpga.viExecution() ) {
        Serial.println("error!");
      }
    }
    else if (inputString.startsWith("viStop")) {
      if( !Fpga.viStop() ) {
        Serial.println("error!");
      }
    }
        
    // clear the string:
    inputString = "";
    stringComplete = false;
  }
  
  yield();
}
          
